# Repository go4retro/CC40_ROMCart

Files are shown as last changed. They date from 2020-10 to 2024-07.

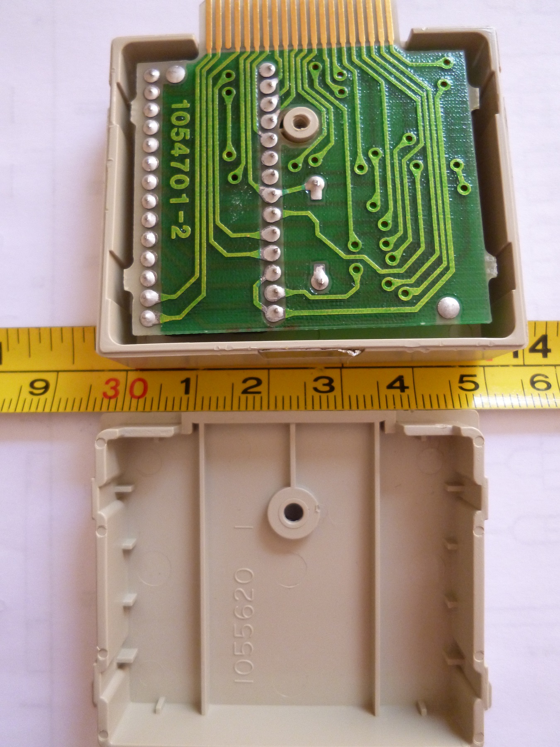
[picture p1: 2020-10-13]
ref/post-48993-0-22288800-1509300595.jpg

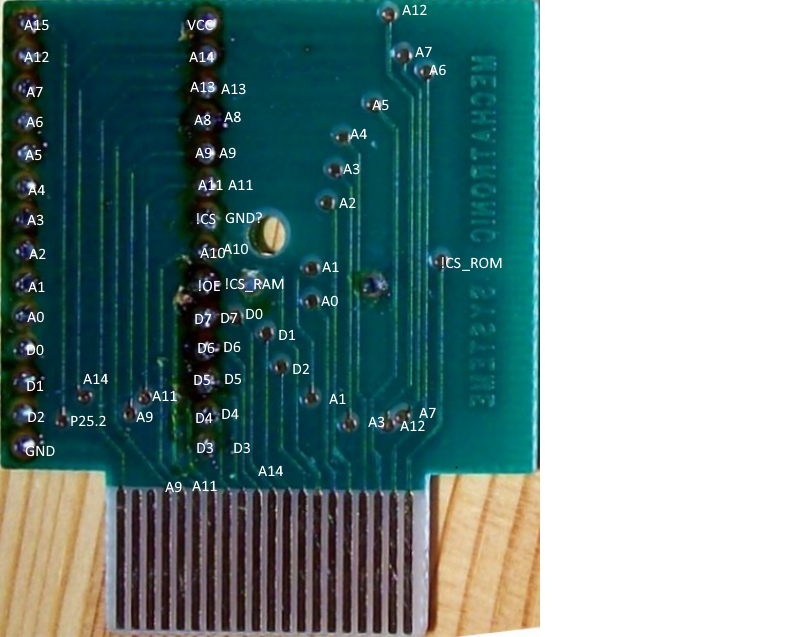
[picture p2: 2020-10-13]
ref/64kB ROM (bottom).png

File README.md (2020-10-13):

## Introduction

Store every ROM cartridge manufactured for the Texas Instruments Compact Computer 40 in a single unit with this mega cartridge. This CC-40 ROM cartridge replicates the functionality of the original application specific ROM cartridge option and also expands it up to 512KB.  Easy access DIP switches on the rear of the unit allow one to select which ROM bank is in use.

Discussion around the design can be reviewed on the AtariAge forum [discussion](https://atariage.com/forums/topic/255728-the-compact-computer-40-cc40/). 

### Main features

- Mimics original PCB location and size
- Up to 512kB ROM capacity
- Easy access to change accessed bank

### Technical Features

- ROM socket can be configured for FLASH or EPROM options
- Optional use of P25.2 and P25.3 signals on cartridge port to select ROM bank

## Purchase

This PCB can be purchased in the [RETRO Innovations Online Store](http://store.go4retro.com/ti-compact-computer-40-prototype-boards/).

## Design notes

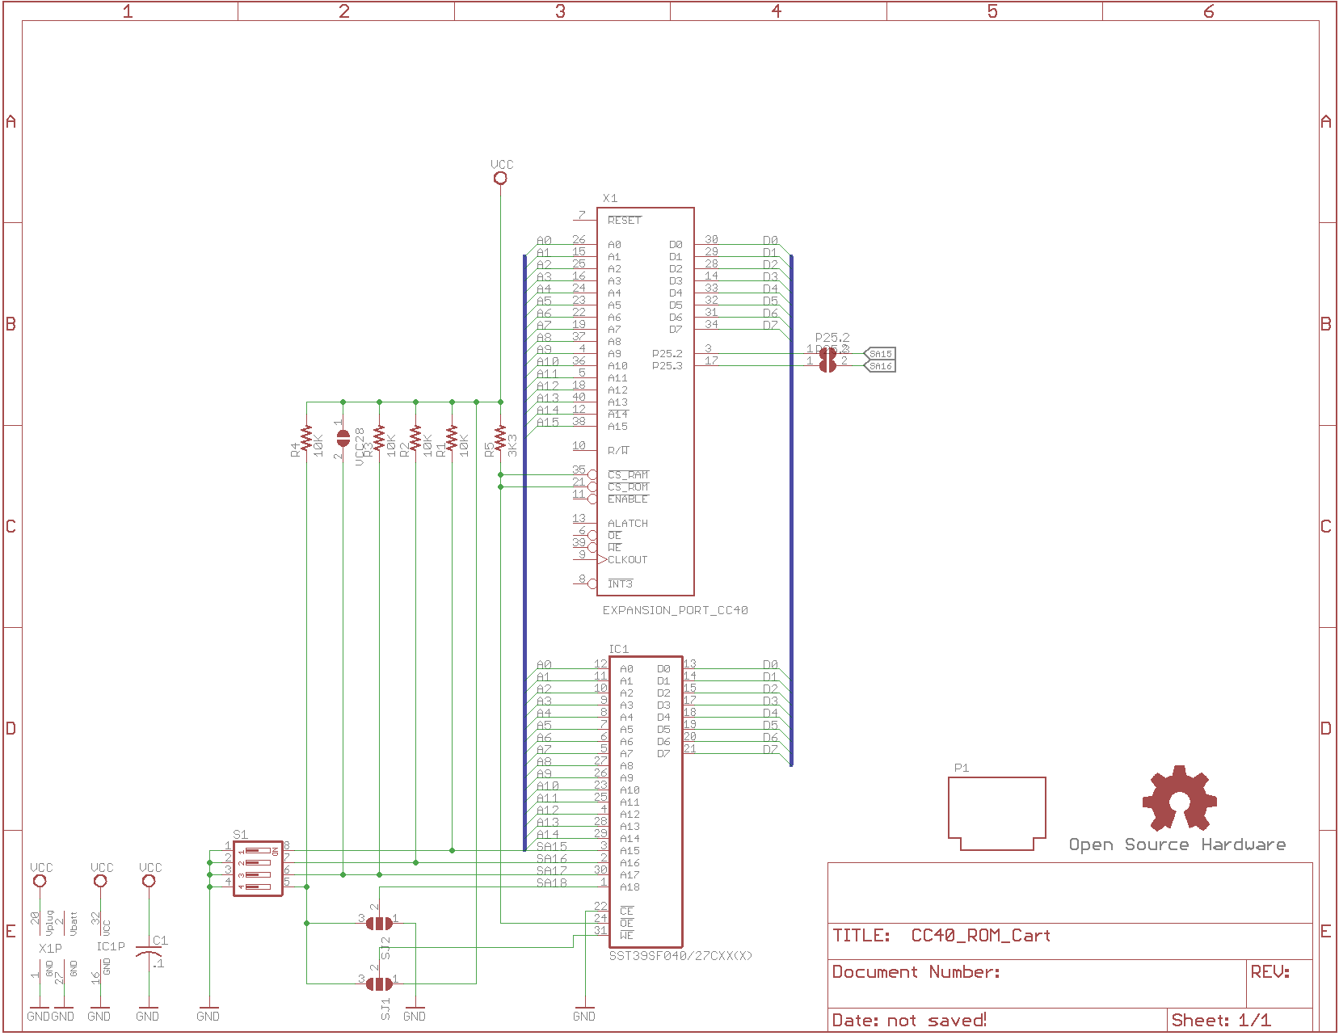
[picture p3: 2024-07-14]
pcb/CC40 ROM Cart Schematic.png

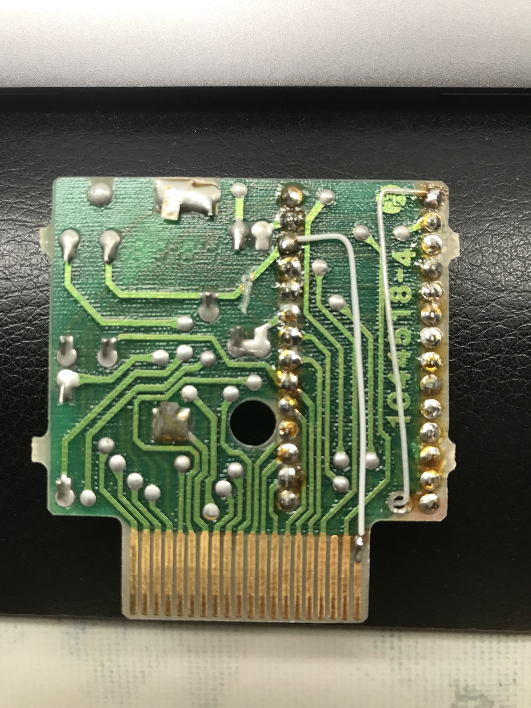
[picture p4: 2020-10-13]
ref/ecccf57daaec4f50453fd8fe46d5e8c4.jpg

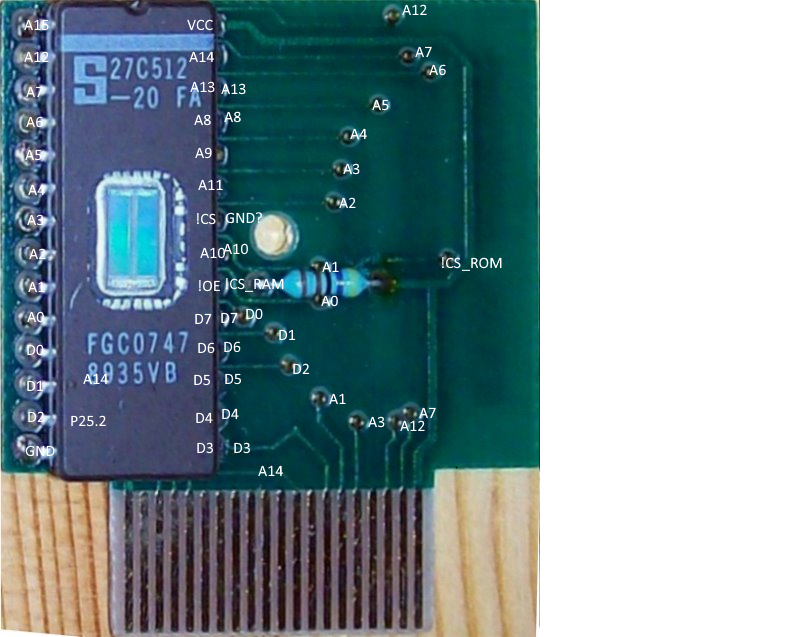
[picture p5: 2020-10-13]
ref/64kB ROM.png

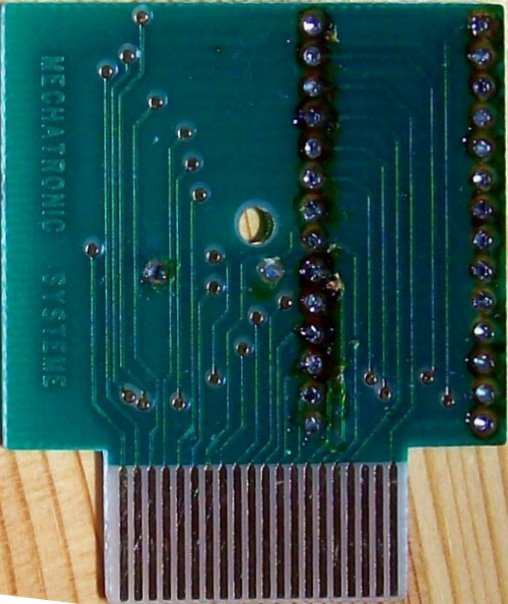
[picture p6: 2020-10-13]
ref/ea-mp back_cropped.jpg

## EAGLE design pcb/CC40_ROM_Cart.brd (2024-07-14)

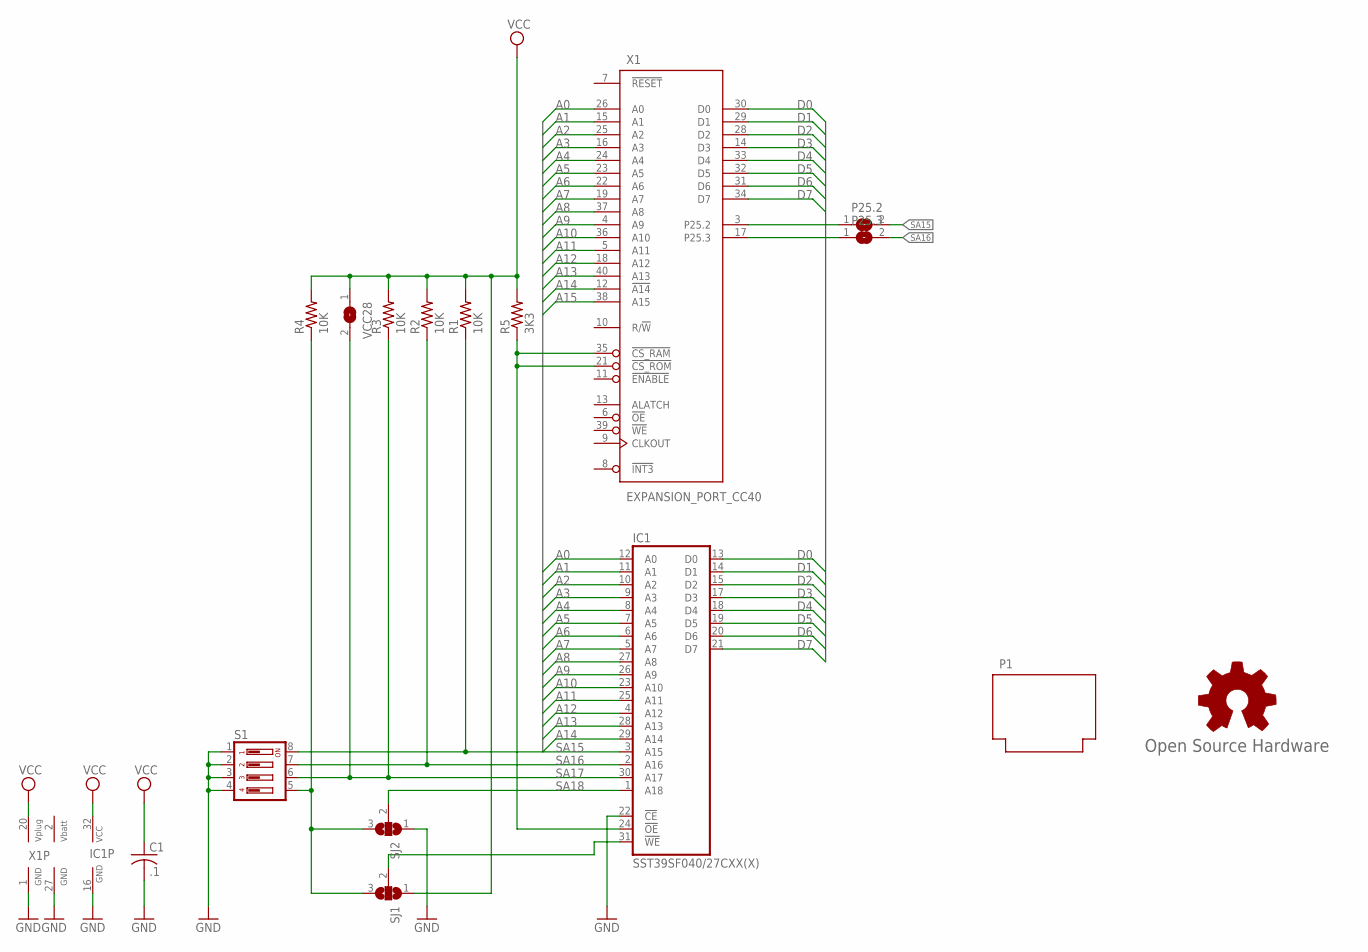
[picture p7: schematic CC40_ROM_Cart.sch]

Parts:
C1: .1; C025-025X050
GOLD_ORB_SM1: Open Source Hardware; OSHW_8MM
IC1: SST39SF040/27CXX(X); DIL32-RP
P1: CC40_CARTN; CC40_CART_NOHOLE
P25.2, P25.3: SJ
R1, R2, R3, R4: 10K; 0204/7
R5: 3K3; 0204/7
S1: DP04; DP-04
SJ1, SJ2: SJ2W; SJ_2
VCC28: SJ
X1: EXPANSION_PORT_CC40; MA20-2(.050)

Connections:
!CS: IC1.24 (!OE), R5.1, X1.21 (!CS_ROM), X1.35 (!CS_RAM)
!WE: IC1.31 (!WE), SJ1.2
A0: IC1.12 (A0), X1.26 (A0)
A1: IC1.11 (A1), X1.15 (A1)
A2: IC1.10 (A2), X1.25 (A2)
A3: IC1.9 (A3), X1.16 (A3)
A4: IC1.8 (A4), X1.24 (A4)
A5: IC1.7 (A5), X1.23 (A5)
A6: IC1.6 (A6), X1.22 (A6)
A7: IC1.5 (A7), X1.19 (A7)
A8: IC1.27 (A8), X1.37 (A8)
A9: IC1.26 (A9), X1.4 (A9)
A10: IC1.23 (A10), X1.36 (A10)
A11: IC1.25 (A11), X1.5 (A11)
A12: IC1.4 (A12), X1.18 (A12)
A13: IC1.28 (A13), X1.40 (A13)
A14: IC1.29 (A14), X1.12 (!A14)
A15: X1.38 (A15)
D0: IC1.13 (D0), X1.30 (D0)
D1: IC1.14 (D1), X1.29 (D1)
D2: IC1.15 (D2), X1.28 (D2)
D3: IC1.17 (D3), X1.14 (D3)
D4: IC1.18 (D4), X1.33 (D4)
D5: IC1.19 (D5), X1.32 (D5)
D6: IC1.20 (D6), X1.31 (D6)
D7: IC1.21 (D7), X1.34 (D7)
GND: C1.2, IC1.16 (GND), IC1.22 (!CE), S1.1, S1.2, S1.3, S1.4, SJ2.1, X1.1 (GND), X1.27 (GND)
SA15: IC1.3 (A15), P25.2.2, R1.1, S1.8
SA15': P25.2.1, X1.3 (P25.2)
SA16: IC1.2 (A16), P25.3.2, R2.1, S1.7
SA16': P25.3.1, X1.17 (P25.3)
SA17: IC1.30 (A17), R3.1, S1.6, VCC28.2
SA18: IC1.1 (A18), SJ2.2
SA18': R4.1, S1.5, SJ1.3, SJ2.3
VBATT: X1.2 (VBATT)
VCC: C1.1, IC1.32 (VCC), R1.2, R2.2, R3.2, R4.2, R5.2, SJ1.1, VCC28.1, X1.20 (VPLUG)

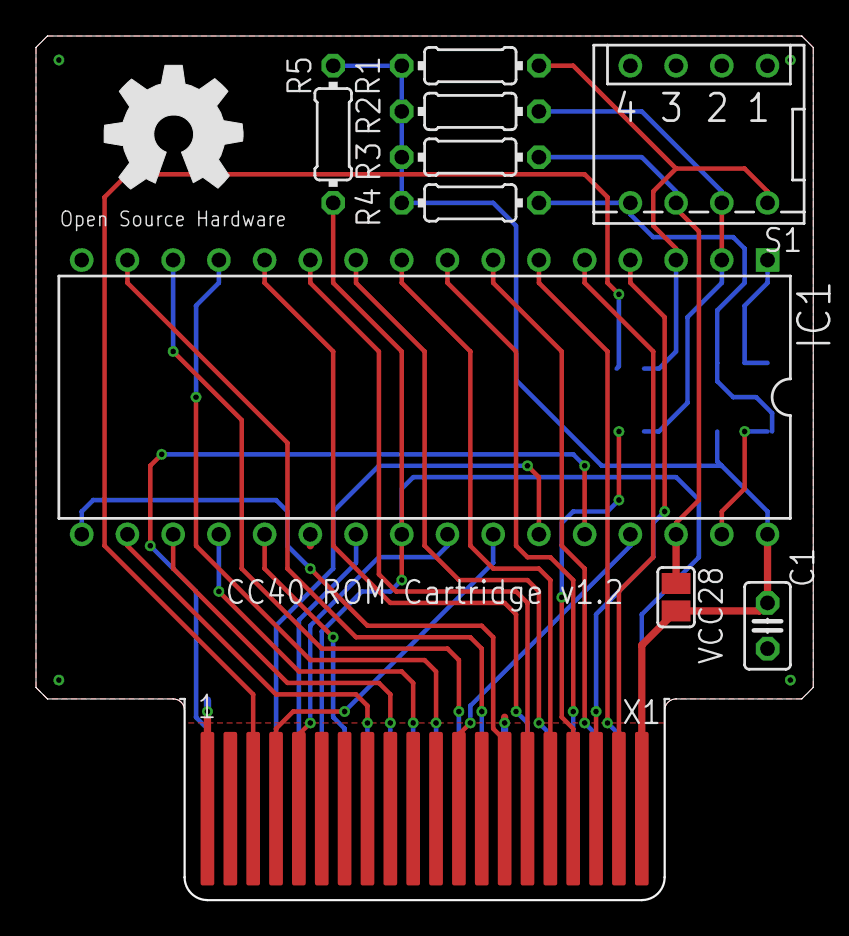
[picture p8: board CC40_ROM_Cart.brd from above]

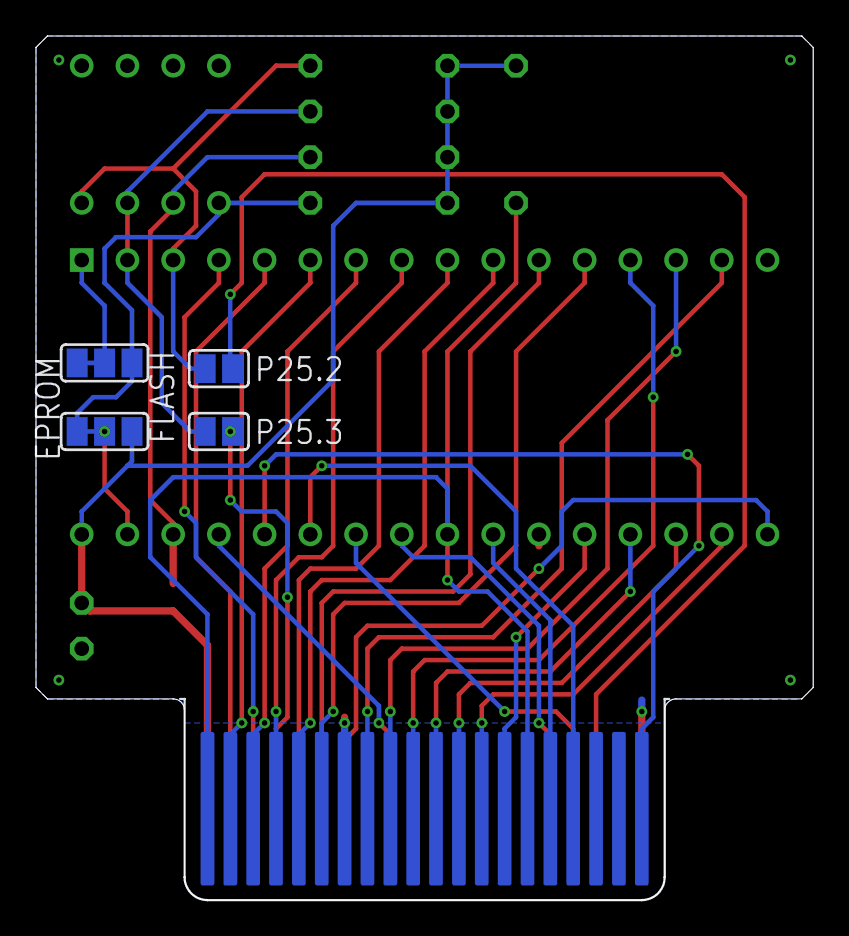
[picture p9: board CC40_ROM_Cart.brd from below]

Board: 2 copper layers, 43.2 x 48.0 mm, 16 parts (4 on the bottom side), 34 nets.

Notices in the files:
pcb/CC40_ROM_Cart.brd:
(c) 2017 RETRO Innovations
